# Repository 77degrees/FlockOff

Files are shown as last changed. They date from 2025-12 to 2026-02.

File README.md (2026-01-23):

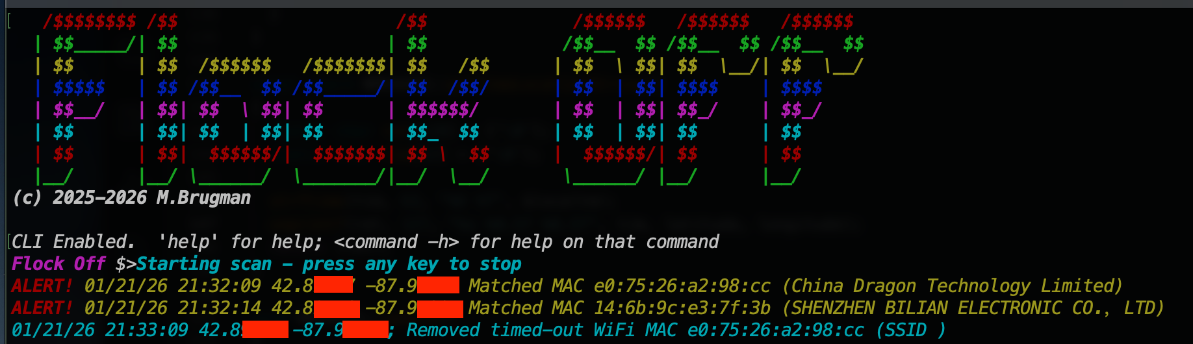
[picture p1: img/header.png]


# FlockOff
This project started as a device specifically to detect Flock security ALPR devices, but has grown into a more generic WiFi/Bluetooth LE scanner/alert wardriving tool.

## Description
This started of strictly as a Flock detector, but grew into more.  In general, it is a device to monitor WiFi and BTLE networks, setting an indicator whenever a broadcaster is found that meets preset parameters.  For WiFi networks, those parameters can be a MAC OID or network name (SSID).  For Bluetooth, the matching criteria can be name, MAC, or by specific 16-bit UUIDs.

The hardware device consists of an ESP32-S3 dev board, a serial GPS module, and two LEDs for alerts and status.

There is a serial interface to the hardware device with a rich CLI (command-line interface).  The device can also be used stand-alone (results are stored to internal file system) or by scripting.

## Project structure
The files contained in the project:
+ `./hardware` - contains a KiCad project for the board
+ `./img` - images used in this README
+ `./py` - simply python3 script to interact with the flocker (notes below)
+ `./src` - source code (arduino project) for the ESP32 (notes below)
+ `./case` - sample 3D printer `.stl` and openSCAD files for a case

### Hardware
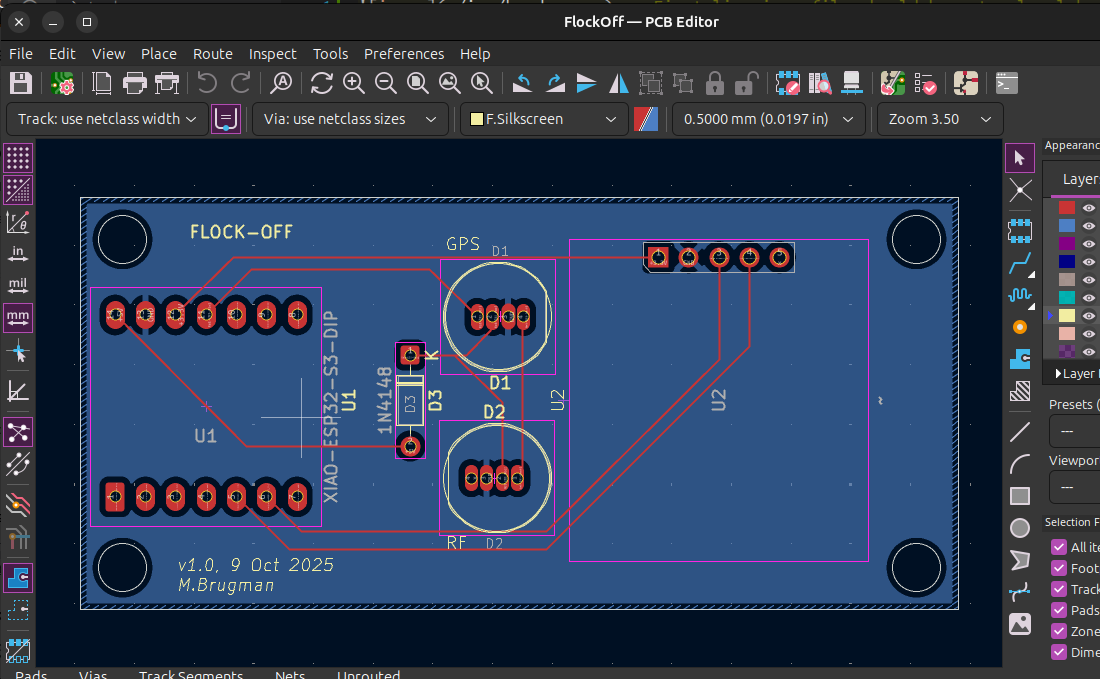
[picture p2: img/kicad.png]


The hardware is dead simple - two dev modules, two through-hole 8mm WS2812 LEDs, and a small signal diode:
+ [ESP32-S3](https://www.amazon.com/Dual-core-Supported-Efficiency-Interface-Robotics/dp/B0DJ6NQFKX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) I picked this module because of small size, good price, and 8MB of both flash and PSRAM
+ [GPS Module](https://www.amazon.com/hiBCTR-Navigation-Positioning-Microcontroller-Sensitivity/dp/B0FL71WTQY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) There is nothing special about this particular module; it is a basic GPS with NMEA serial interface, it was cheap, and in stock at Amazon
+ [WS1812 LEDs](https://www.adafruit.com/product/1734)  These are interesting in that they are the typical addressable LEDs, but in a through-hole 8mm package.  They are great for using as status indicators.  Also handy because there are so many libraries to work with them.
+ [1N4148 Diode](amazon.com/ALLECIN-1N4148-Schottky-Switching-Package/dp/B0CKRMK45V/ref=sr_1_6_sspa?dib=eyJ2IjoiMSJ9.5f18Rx_7lMSBN-40Nk5_scirzd5gVqG_sr48GsP-pxJ7RyARr5GHbm76WgpJle4ywCwcEGfv6m5ZR-PIBoBmRN28qtEe29DQYY84c263_q6oFDujaGGVK8-qabhrRd_IZtu2PwFHkKMBdiIw8IDQjSYkBxPm9DKi_AA6exCA7rmOiWGNdN9Oq0D-5c1H1XGK1kBii_ftCc-F3YiORaBovQ5vkFW9kAN3zzAu7IgDKEk.RF6rc4KmtAVvY9uUuLV-Zf6xt-HBLaOGQf1vvRW5V2U&dib_tag=se&keywords=1n4148&qid=1765833550&sr=8-6-spons&sp_csd=d2lkZ2V0TmFtZT1zcF9tdGY&psc=1) (Amazon link for reference, I had some in my parts bin).  This is used because it has a forward voltage drop of about .7V.

#### What's up with the diode?
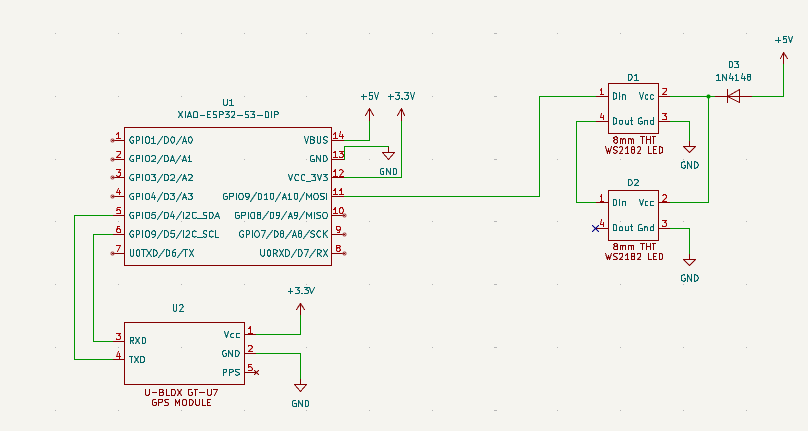
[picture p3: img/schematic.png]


Like pretty much all WS2812 LEDs, these need 5VDC to operate; 5VDC power, 5VDC data line.  The ESP32 is a 3.3 microcontroller, so what to do?

The USB connection supplies 5V which is regulated down to 3.3V for the microcontroller and associated stuff.  In the schematic above, `D3` is shown between the 5V USB power and the LED power in pin; that drops the voltage to about 4.3VDC.  That's just within spec for the LED, and it is still plenty bright.

The 3.3V signal data line from the ESP32 would be too low if the LED was powered by 5V, but is within spec for the LED when it is running at 4.3-ish volts.  It's a cheat to get away without having to use level converters; not something I'd do for a "real" production project, but good enough for here.

### Firmware
The firmware is written using the Arduino IDE.  In the past, I've always avoided that and used VS Code with my own Makefile or CMAKE, PlatformIO, or whatever.  I decided to go with Arduino in this case because I'm very unhappy with the integration of Copilot into VS Code (and really, the push to shove AI into everything).  For now, Ardiuno is just code.

For more specific information, see the `DEVELOPING.md` file.

### CLI Interface
There is a CLI available at the USB port at 115200/8N1.  The CLI uses ANSII escape codes for color, has tab-completion, up-arrow recall, and help:
```  
Flock Off $>help 
Use 'command -h' for detailed help on each command
        help - Print list of commands
        version - Display firmware version
        survey - Perform WiFi survey
        scan - Start continuous scan
        clear - Clear the console
        reset - Reboot the device
        ls - List files
        rm - Delete file
        write - Write test file
        mv - Rename file
        cp - Copy file
        cat - Cat file
        status - Get system status
        config - Get/Set config values
        criteria - Get/Set target matching criteria
```  
Passing a `-h` to any command will show help for that command, for example:
```  
Flock Off $>survey -h
survey [OPTION]
Perform a WiFi and/or Bluetooth survey.  Displays all results, not just those that match scan criteria.

  -i <INTERVAL>   interval in milliseconds to scan each WiFi channel
  -f <FILENAME>   save results to FILENAME in JSON format
  -n <NOTES>      add NOTES added for reference

If the -f parameter is not passed, JSON results will be displayed in the terminal.
```  
There is a flat filesystem included (flat, meaning no directories; all files are in a single directory). Basic Linux-type file management commands are available, but note that there is no 'globbing'; all filenames must be directly entered.  Examples:
```  
      371  01/22/26  18:25:46  autoscan.1.log
      163  01/22/26  18:42:01  autoscan.log
      208  12/31/69  18:02:32  config.json
    11300  01/22/26  18:26:04  system.1.log
    11107  01/22/26  18:25:30  system.2.log
    11347  01/22/26  18:43:37  system.log
Flock Off $>cat config.json
{"deviceName":"Super Secret Sniffer","timeZone":"CST6CDT,M3.2.0,M11.1.0","LEDBrightness":100,"debugEnabled":true,"debugLogRollCount":3,}
Flock Off $>
```  
Configuration is menu-driven:
```  
Flock Off $>config 
1) Set device name (Super Secret Sniffer)
2) Set timezone (CST6CDT,M3.2.0,M11.1.0)
3) Set max LED brightness (100)
4) Set debug logging (enabled)
5) Set scan logging (enabled)
6) Set debug file rolling count (3)
7) Set scan file rolling count (10)
8) Set minimum RSSI (-90)
9) Set minimum alert time (60)
Select number of item to change or 'x' to exit with no changes: 
```  
## LEDs
What do the LEDs do?
### GPS LED
| color | description |  
|---|---|
| Green blink | GPS Fix good, communication good |  
| Purple blink | GPS no fix, communication good |  
| Red blink | No comms to GPS module |  

### RF LED
| color | description |  
|---|---|
| Blue fade alert | Survey in progress | 
| Steady blue | Continuous scan in progress |  
| Alternating blue/purple | Continuous scan detecting target |  

## Continuous scans
The default action for the device is to continuously scan for targets in the area.  There are two ways to start a scan:
+ Power up the device, if no input is seen on the CLI in the first 5 seconds, continuous scanning will automatically begin
+ Using the `scan` command to start continuous scanning

### Stopping a scan
Press any key will connected to the serial port to stop the scan

### Scan logging and information
The RF LED will glow continuously blue when a scan is running.  If a target is seen, the LED will alternate blue/purple.  As targets are seen and "disappear" they will be listed in the serial terminal.  If enabled in configuration, the data will also be saved in rolling files in the filesystem - this allows "headless" operation with the ability to look at the results later.

Sample output in the serial terminal:
```  
Flock Off $>Starting scan - press any key to stop
ALERT! 01/23/26 01:03:13 42.8XXXX -87.9XXXX Matched MAC 14:6b:9c:e3:7f:3b (SHENZHEN BILIAN ELECTRONIC CO.，LTD)
```  

Sample scan log:  
```  
Flock Off $>ls 
      267  01/22/26  19:02:59  autoscan.1.log
      163  01/22/26  18:42:01  autoscan.2.log
      371  01/22/26  18:25:46  autoscan.3.log                                             
      267  01/22/26  19:04:01  autoscan.log                                               
      208  12/31/69  18:02:32  config.json                                                
     4557  01/22/26  18:50:13  survey.example.json                                        
    12384  01/22/26  19:03:01  system.1.log                                               
    11300  01/22/26  18:26:04  system.2.log
    11215  01/22/26  19:04:01  system.log
Flock Off $>cat autoscan.log
[00007907] 01/22/26 19:03:13 LOGGER::Started logger
[00007950] 01/22/26 19:03:13 WIFI::01/23/26 01:03:13 42.8XXXX -87.9XXXX; Matched mac 14:6b:9c:e3:7f:3b
[00055504] 01/22/26 19:04:01 SCAN::Ending scan, closing log.
[00055516] 01/22/26 19:04:01 LOG::Closing log!
```  

## Performing a site survey
A survey will report all WiFi and BTLE broadcasters in range.  Why perform a survey?  Maybe there's a known device that isn't triggering alerts, and we want to characterize it (find MAC address, if BT, see if there are any service UUIDs it's broadcasting).

Basic steps:
1) Connect to the device with a serial terminal of your choice (PuTTY on Windows, TIO/minicom on Linux, minicom on MAC).
2) Use the `status` command to be sure GPS has gotten a fix and that the data looks correct (GPS coordinates masked by me for privacy):
``` 
Flock Off $>status 
->Hardware:
        Chip model ESP32-S3
        Chip frequency 240 MHz
        Core count 2 cores
->GPS:
        GPS current coordinates are 42.8XXXX, -87.9XXXX
        GPS current time/date (gmt) is 00:47:52 1/23/2026
        Number of satellites currently tracked: 9
->Filesystem:
        Total capacity 4194304bytes, 53248 used (4044 KiB free)
->Memories:
        Internal total heap 324436 bytes, 88536 used (230 KiB free)
        PSRAM total heap 8388608 bytes, 58280 used (8192 KiB free)
->Wall clock:
        Current wall clock time is Thu, 22 Jan 2026 18:47:51 -0600
        Timezone is set to CST6CDT,M3.2.0,M11.1.0
```  
3) Use the `survey` command to start the survey.  Parameters are:
   + `-i INTERVAL` defines how much time (milliseconds) to spend on each WiFi channel
   + `-n NOTES` to save the results in a JSON file, with survey notes set to `NOTES`
   + `-f FILENAME` to save results
```  
Flock Off $>survey -i 2000 -n 'Example survey' -f survey.example.json
Survey starting
Survey done, found 16 WiFi devices, 13 Bluetooth devices.
Saving survey results to survey.example.json
Wrote 4557 bytes to file
```  
This example survey found 16 WiFi devices and 13 BTLE devices.  The data in the JSON file looks like this:  
```
Flock Off $>cat survey.example.json
{"SurveyNotes":"'Example survey","Device":"Super Secret Sniffer","LocationLongLat":[-87.9XXXX,42.8XXXX],"SatelliteCount":9,"DateTime":"2026-01-22 18:50:13","Timezone":"CST6CDT,M3.2.0,M11.1.0","DataVersion":2,"WiFiDevices":[{"Method":"WiFi","Type":"Data","Subtype":"ND (null no data)","SSID":"","SourceAddr":"4a:43:76:15:87:dd","DestAddr":"a0:36:bc:db:ca:a4","Channel":10,"RSSI":-20},{"Method":"WiFi","Type":"Management","Subtype":"beacon","SSID":"Open Wheel","SourceAddr":"08:36:c9:ed:b8:65","DestAddr":"ff:ff:ff:ff:ff:ff","Channel":4,"RSSI":-87},{"Method":"WiFi","Type":"Management","Subtype":"beacon","SSID":"NETGEAR05-Guest","SourceAddr":"c2:18:65:d2:d2:b2","DestAddr":"ff:ff:ff:ff:ff:ff","Channel":2,"RSSI":-87},{"Method":"WiFi","Type":"Data","Subtype":"Data","SSID":"","SourceAddr":"b2:28:aa:1c:0a:2a","DestAddr":"01:80:c2:00:00:00","Channel":1,"RSSI":-63},{"Method":"WiFi","Type":"Management","Subtype":"beacon","SSID":"flu","SourceAddr":"b2:28:aa:1c:0a:29","DestAddr":"ff:ff:ff:ff:ff:ff","Channel":1,"RSSI":-63},{"Method":"WiFi","Type":"Data","Subtype":"Data","SSID":"","SourceAddr":"a0:36:bc:db:ca:a0","DestAddr":"01:80:c2:00:00:00","Channel":6,"RSSI":-45},{"Method":"WiFi","Type":"Management","Subtype":"beacon","SSID":"virus","SourceAddr":"a0:36:bc:db:ca:a0","DestAddr":"ff:ff:ff:ff:ff:ff","Channel":6,"RSSI":-45},{"Method":"WiFi","Type":"Management","Subtype":"beacon","SSID":"flu_IoT","SourceAddr":"b2:28:aa:1c:0a:2a","DestAddr":"ff:ff:ff:ff:ff:ff","Channel":1,"RSSI":-64},{"Method":"WiFi","Type":"Data","Subtype":"QoS Data","SSID":"","SourceAddr":"b2:28:aa:1c:0a:29","DestAddr":"e0:75:26:a2:98:cc","Channel":1,"RSSI":-63},{"Method":"WiFi","Type":"Data","Subtype":"QoS Data","SSID":"","SourceAddr":"14:6b:9c:e3:7f:3b","DestAddr":"b2:28:aa:1c:0a:29","Channel":1,"RSSI":-54},{"Method":"WiFi","Type":"Data","Subtype":"QoS Data","SSID":"","SourceAddr":"cc:db:a7:93:ec:2c","DestAddr":"a0:36:bc:db:ca:a0","Channel":7,"RSSI":-71},{"Method":"WiFi","Type":"Management","Subtype":"beacon","SSID":"<HIDDEN>","SourceAddr":"cc:28:aa:1c:0a:28","DestAddr":"ff:ff:ff:ff:ff:ff","Channel":1,"RSSI":-63},{"Method":"WiFi","Type":"Data","Subtype":"Data","SSID":"","SourceAddr":"a0:8a:06:6f:ec:fa","DestAddr":"01:00:5e:00:00:07","Channel":6,"RSSI":-84},{"Method":"WiFi","Type":"Data","Subtype":"Data","SSID":"","SourceAddr":"cc:28:aa:1c:0a:28","DestAddr":"01:80:c2:00:00:00","Channel":1,"RSSI":-64},{"Method":"WiFi","Type":"Data","Subtype":"ND (null no data)","SSID":"","SourceAddr":"e0:75:26:a2:98:cc","DestAddr":"b2:28:aa:1c:0a:29","Channel":1,"RSSI":-76},{"Method":"WiFi","Type":"Management","Subtype":"beacon","SSID":"NETGEAR05","SourceAddr":"94:18:65:d2:d2:b1","DestAddr":"ff:ff:ff:ff:ff:ff","Channel":2,"RSSI":-90}],"BLEDevices":[{"Method":"BTLE","Name":"N00DM","MAC":"c7:06:90:c0:c4:6c","RSSI":-84,"UUID16bit":[65199],"UUID128bit":[],"DataUUID16bit":[65199],"DataUUID128bit":[]},{"Method":"BTLE","Name":"OfficeJet 5200 series","MAC":"86:a9:3e:bc:5c:c9","RSSI":-86,"UUID16bit":[65144],"UUID128bit":[],"DataUUID16bit":[],"DataUUID128bit":[]},{"Method":"BTLE","Name":"","MAC":"47:d1:13:3a:79:de","RSSI":-70,"UUID16bit":[],"UUID128bit":[],"DataUUID16bit":[],"DataUUID128bit":[]},{"Method":"BTLE","Name":"","MAC":"6b:7a:e6:9b:f5:d2","RSSI":-65,"UUID16bit":[],"UUID128bit":[],"DataUUID16bit":[],"DataUUID128bit":[]},{"Method":"BTLE","Name":"","MAC":"66:95:29:56:70:e9","RSSI":-69,"UUID16bit":[],"UUID128bit":[],"DataUUID16bit":[],"DataUUID128bit":[]},{"Method":"BTLE","Name":"","MAC":"d4:0a:5d:22:d4:e9","RSSI":-61,"UUID16bit":[],"UUID128bit":[],"DataUUID16bit":[],"DataUUID128bit":[]},{"Method":"BTLE","Name":"","MAC":"63:13:27:3d:4d:22","RSSI":-62,"UUID16bit":[],"UUID128bit":[],"DataUUID16bit":[],"DataUUID128bit":[]},{"Method":"BTLE","Name":"","MAC":"1d:2a:e8:54:5e:f4","RSSI":-69,"UUID16bit":[],"UUID128bit":[],"DataUUID16bit":[65267],"DataUUID128bit":[]},{"Method":"BTLE","Name":"","MAC":"a8:51:ab:c6:11:25","RSSI":-75,"UUID16bit":[],"UUID128bit":[],"DataUUID16bit":[],"DataUUID128bit":[]},{"Method":"BTLE","Name":"","MAC":"3c:5c:ae:fd:ff:0d","RSSI":-53,"UUID16bit":[],"UUID128bit":[],"DataUUID16bit":[64753],"DataUUID128bit":[]},{"Method":"BTLE","Name":"","MAC":"79:d2:f7:d7:5d:22","RSSI":-75,"UUID16bit":[],"UUID128bit":[],"DataUUID16bit":[],"DataUUID128bit":[]},{"Method":"BTLE","Name":"","MAC":"32:2b:12:15:81:9a","RSSI":-51,"UUID16bit":[],"UUID128bit":[],"DataUUID16bit":[64753],"DataUUID128bit":[]},{"Method":"BTLE","Name":"[TV] Samsung 8 Series (65)","MAC":"8c:ea:48:a7:2c:03","RSSI":-72,"UUID16bit":[],"UUID128bit":[],"DataUUID16bit":[],"DataUUID128bit":[]}]}
```  
### Interpreting survey results
The included python scripts can pull the survey data from the device and populate some database tables (sqlite3) for analysis.

To do this, start by going to the `./py` directory and running the script.  There are some Python modules needed; they can be installed with the included requirements file (`pip3 install -r requirements.txt`)

*Note - it is always recommended to use a virtual environment with python scripts that require different modules.  See python documentation on how to create and use a virtual environment if necessary.*

Start by listing the files on the device (make sure you are no longer connected to it by serial terminal):
```  
┌──(venv)─(matty💊s76)-[~/data/projects/FlockOff/py]
└─$ python3 ./flock.py --dbfile example.db --port /dev/ttyACM0 --dir                
config.bak
config.json
survey.00.json
survey.01.json
survey.example.json
system.log
```  
The parameters to the `flock.py` script are:
+ `--port PORT` - the serial port of the connected device
+ `--dbfile FILE` - name of the database file to use (it will be created if it does not exist).  This is only required if the `load` command is issued.
+ Command - this is one of a few commands:
  + `--dir` - list the files on the device
  + `--cat FILE` - list the contents of the specified file
  + `--load FILE` - load the specified JSON file into database tables'
  + `--download FILE` - download the specified FILE from the device to the local filesystem.  The local copy will have the same name as the file on the device.

The above `--dir` command showed our `survey.example.json` from the survey.  Let's load it into the database tables:
```  
┌──(venv)─(matty💊s76)-[~/data/projects/FlockOff/py]
└─$ python3 ./flock.py --dbfile example.db --port /dev/ttyACM0 --load survey.example.json
Loaded 12 WiFi devices, 21 BTLE devices from survey "'Example" at 2025-12-15 15:56:52
```  

Note that if the database file didn't exist before this command, the script will also populate the data tables with the YAML and JSON files for known manufacturer OID and UUID data.

### Survey database
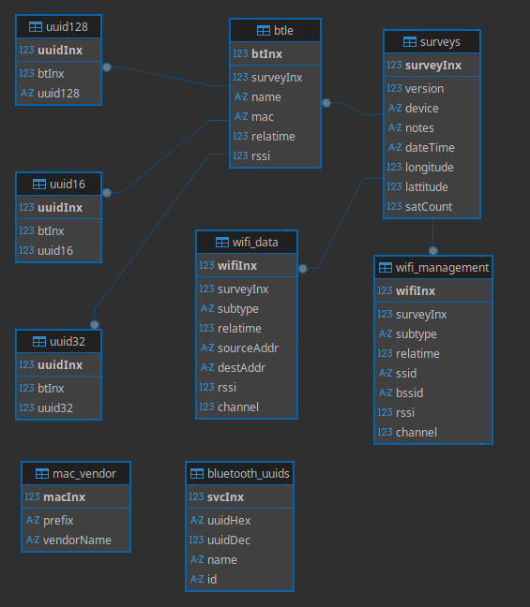
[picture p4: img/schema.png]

The database schema can be seen in `./src/py/survey.db.schema`

The sqlite3 database can be explored with a gui tool or the command line.  The `surveys` table shows basic information about the a survey json file (using `sqlite3` command line tool):
```  
sqlite> .mode box
sqlite> .headers on
sqlite> select * from surveys;
┌───────────┬──────────┬─────────────────────┬───────────┬───────────┬──────────┐
│ surveyInx │  notes   │      dateTime       │ longitude │ lattitude │ satCount │
├───────────┼──────────┼─────────────────────┼───────────┼───────────┼──────────┤
│ 1         │ 'Example │ 2025-12-15 15:56:52 │ 42.0001   │ -87.0001  │ 8        │
└───────────┴──────────┴─────────────────────┴───────────┴───────────┴──────────┘
```  
 The `surveyInx` field is a foreign key into the `wifi_data`, `wifi_management` and `btle` tables.  This allows multiple surveys to be loaded into a single database file

`notes` is the value from the `-j NOTES` parameter of the `survey` command.  `dateTime`, `longitude`, `lattitude`, and `satCount` are populated by the GPS module.

`wifi_data` contains all captured WiFi Data packets; `wifi_management` contains all captured WiFi Management packets (think access point beacons, probe responses, etc.).  They can be joined to find all devices and the access points to which they are connected:   
```
select distinct sta.subtype "station data subtype",
		ap.ssid "AP SSID", 
		ap.bssid "AP BSSID", 
		sta.sourceAddr "station MAC", 
		sta.channel "CH",
		mv.vendorName "station vendor" 
from wifi_data sta
join wifi_management ap on ap.bssid = sta.destAddr and ap.channel = sta.channel and ap.surveyInx = sta.surveyInx
left join mac_vendor mv on mv.prefix like substr(sta.sourceAddr, 1, 8) 
where sta.surveyInx = 2
order by ap.bssid;

┌──────────────────────┬────────────────────┬───────────────────┬───────────────────┬────┬────────────────────────────────────────┐
│ station data subtype │      AP SSID       │     AP BSSID      │    station MAC    │ CH │             station vendor             │
├──────────────────────┼────────────────────┼───────────────────┼───────────────────┼────┼────────────────────────────────────────┤
│ ND (null no data)    │ virus              │ a0:36:bc:db:ca:a0 │ cc:db:a7:93:ec:2c │ 6  │ Espressif Inc.                         │
│ QoS Data             │ virus              │ a0:36:bc:db:ca:a0 │ cc:db:a7:93:ec:2c │ 6  │ Espressif Inc.                         │
│ ND (null no data)    │ SpectrumSetup-ECFD │ a0:8a:06:6f:ec:fa │ bc:35:1e:77:8a:9f │ 6  │ Tuya Smart Inc.                        │
│ ND (null no data)    │ SpectrumSetup-ECFD │ a0:8a:06:6f:ec:fa │ 30:fc:eb:84:38:ce │ 7  │ LG Electronics (Mobile Communications) │
│ ND (null no data)    │ SpectrumSetup-ECFD │ a0:8a:06:6f:ec:fa │ 30:fc:eb:84:38:ce │ 6  │ LG Electronics (Mobile Communications) │
│ QoS Data             │ flu                │ b2:28:aa:1c:0a:29 │ e0:75:26:a2:98:cc │ 1  │ China Dragon Technology Limited        │
│ ND QoS               │ flu                │ b2:28:aa:1c:0a:29 │ 14:6b:9c:e3:7f:3b │ 2  │ SHENZHEN BILIAN ELECTRONIC CO.，LTD    │
│ QoS Data             │ flu                │ b2:28:aa:1c:0a:29 │ 14:6b:9c:e3:7f:3b │ 1  │ SHENZHEN BILIAN ELECTRONIC CO.，LTD    │
│ QoS Data             │ flu                │ b2:28:aa:1c:0a:29 │ 18:b4:30:a0:24:fa │ 1  │ Nest Labs Inc.                         │
└──────────────────────┴────────────────────┴───────────────────┴───────────────────┴────┴────────────────────────────────────────┘
```

The `btle` table contains bluetooth broadcasters:
```  
sqlite> select b.name, b.mac, b.rssi from btle as b join surveys s on b.surveyInx = s.surveyInx order by b.mac;
┌───────────────────────┬───────────────────┬──────┐
│         name          │        mac        │ rssi │
├───────────────────────┼───────────────────┼──────┤
│                       │ 01:c5:61:6d:2c:b4 │ -53  │
│                       │ 04:a0:29:10:68:e4 │ -78  │
│                       │ 08:66:98:f2:a3:ba │ -84  │
│                       │ 34:fe:3e:a1:f5:e2 │ -63  │
│                       │ 56:f6:b3:ad:60:5f │ -82  │
│                       │ 66:7f:66:1d:ec:ce │ -68  │
│                       │ 6d:67:db:fd:9e:67 │ -84  │
│                       │ 6e:d3:64:c3:af:77 │ -79  │
│                       │ 77:50:8c:84:fa:72 │ -45  │
│                       │ 78:90:0b:c0:26:1b │ -69  │
│                       │ 7e:91:43:7c:ff:bf │ -75  │
│ OfficeJet 5200 series │ 86:a9:3e:bc:5c:c9 │ -76  │
│                       │ 8c:ea:48:a7:2c:03 │ -73  │
│                       │ a8:51:ab:c6:11:25 │ -82  │
│                       │ c0:c9:9b:f2:d7:43 │ -75  │
│                       │ c1:cf:e2:c9:64:5f │ -85  │
│                       │ ca:ba:59:12:f6:0d │ -66  │
│ N00DM                 │ ce:a3:ad:95:04:29 │ -80  │
│                       │ d5:93:9d:03:9f:f5 │ -80  │
│                       │ ea:a8:d0:6f:67:89 │ -84  │
│                       │ ec:9d:4d:3c:28:2b │ -68  │
└───────────────────────┴───────────────────┴──────┘
```  
There are quite a few BTLE devices found.  To narrow it down to those that are broadcasting a UUID:
```  
sqlite> select b.name, b.mac, u.uuid16 from btle b join uuid16 u on b.btInx = u.btInx where b.surveyInx = 1 order by b.mac;
┌───────────────────────┬───────────────────┬────────┐
│         name          │        mac        │ uuid16 │
├───────────────────────┼───────────────────┼────────┤
│ OfficeJet 5200 series │ 86:a9:3e:bc:5c:c9 │ 65144  │
│ N00DM                 │ ce:a3:ad:95:04:29 │ 65199  │
└───────────────────────┴───────────────────┴────────┘
```

**More SQL examples can be found in `./example.sql`**

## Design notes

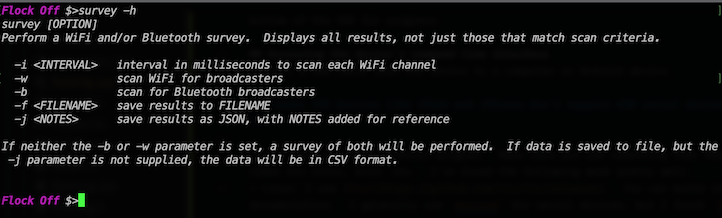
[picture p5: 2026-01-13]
img/terminal2.png

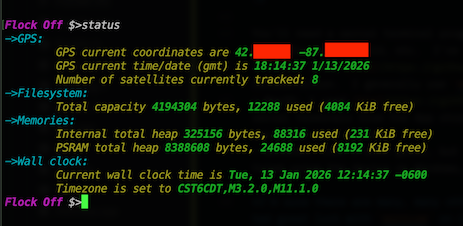
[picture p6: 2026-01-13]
img/terminal.png

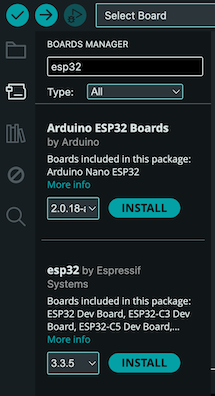
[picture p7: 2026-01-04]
img/boards.png

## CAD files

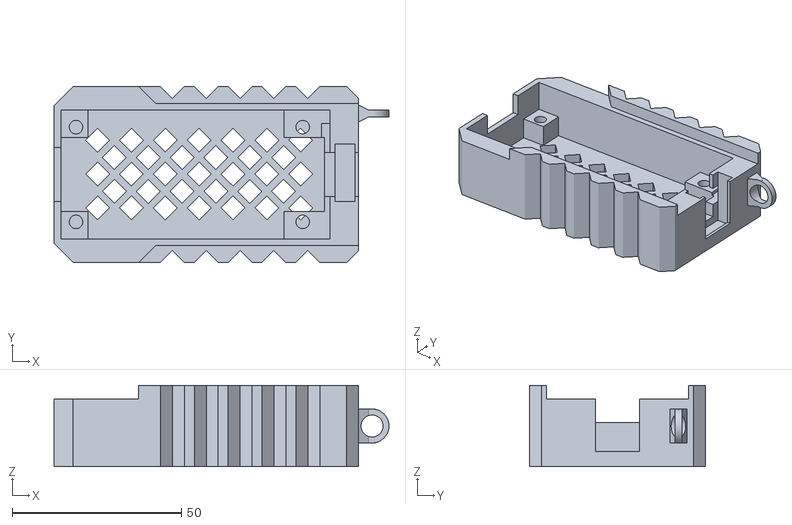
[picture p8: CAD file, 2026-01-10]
case/bottom.stl
99.0 x 52.0 x 24.0

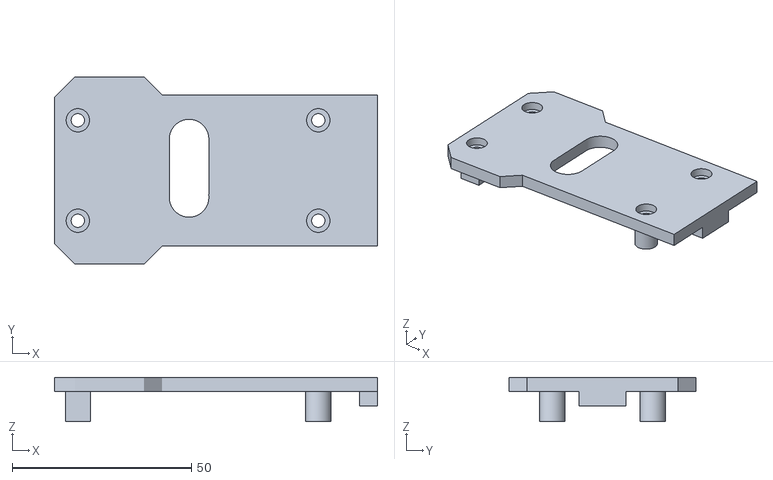
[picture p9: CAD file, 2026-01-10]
case/top.stl
90.0 x 52.0 x 12.4

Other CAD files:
case/case.scad

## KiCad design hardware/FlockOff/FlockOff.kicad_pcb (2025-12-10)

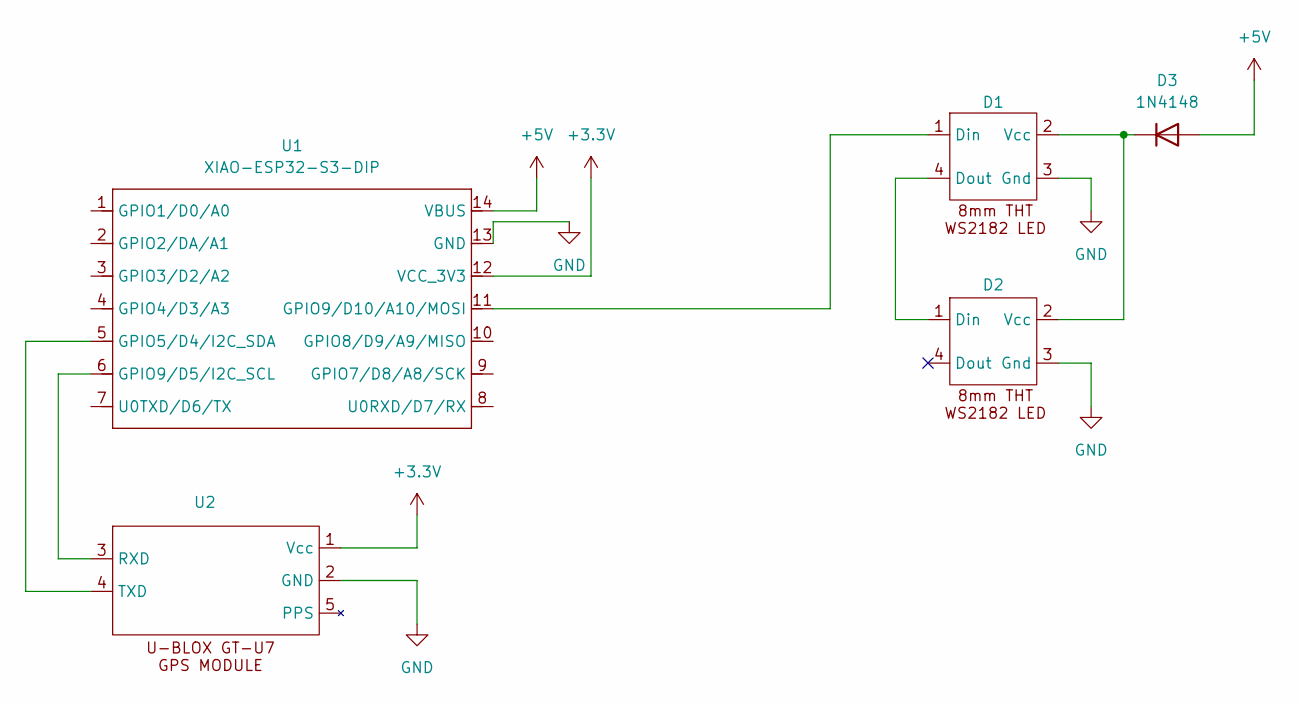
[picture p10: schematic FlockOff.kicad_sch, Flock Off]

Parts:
D1, D2: LED_D8.0mm_WS2812
D3: 1N4148; D_DO-35_SOD27_P7.62mm_Horizontal
U1: XIAO-ESP32-S3-DIP; MOUDLE14P-XIAO-DIP-SMD
U2: GPS_Module

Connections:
+3.3V: U1.12 (VCC_3V3), U2.1 (Vcc)
+5V: D3.2 (A), U1.14 (VBUS)
GND: D1.3 (Gnd), D2.3 (Gnd), U1.13 (GND), U2.2 (GND)
unnamed: D1.1 (Din), U1.11 (GPIO9/D10/A10/MOSI)
unnamed: D1.4 (Dout), D2.1 (Din)
unnamed: D1.2 (Vcc), D2.2 (Vcc), D3.1 (K)
unnamed: U1.5 (GPIO5/D4/I2C_SDA), U2.4 (TXD)
unnamed: U1.6 (GPIO9/D5/I2C_SCL), U2.3 (RXD)

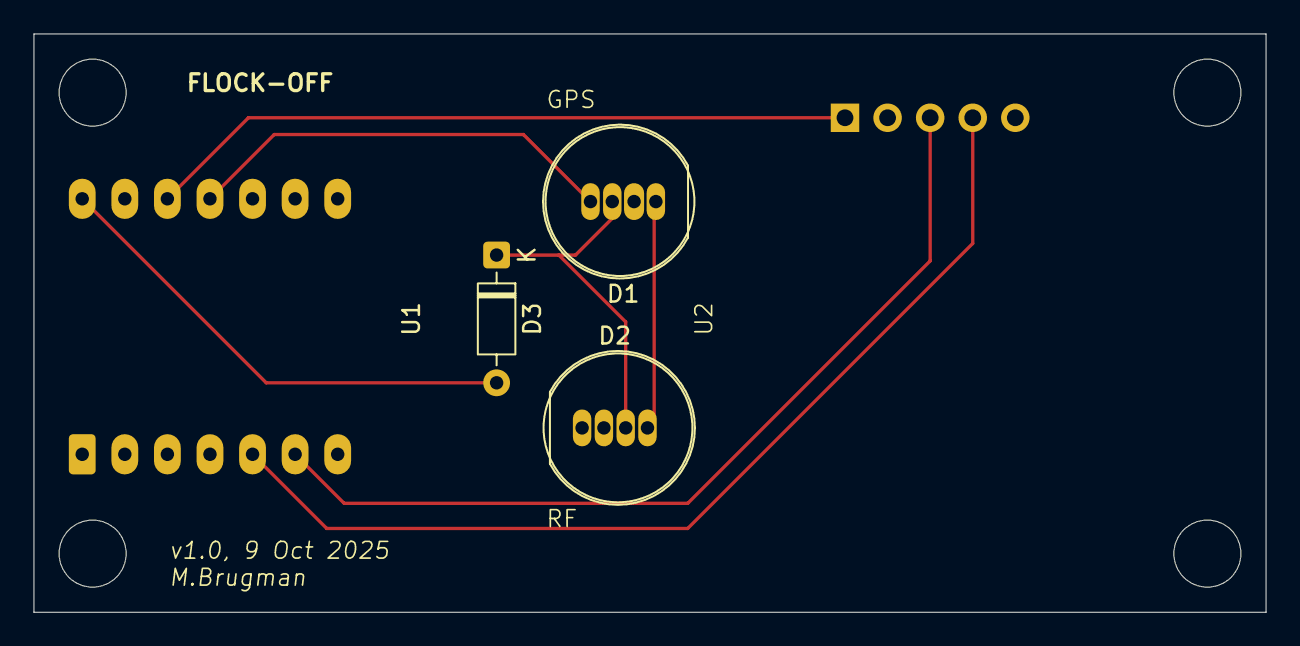
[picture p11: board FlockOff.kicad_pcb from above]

Board: 2 copper layers, 73.5 x 34.5 mm, 5 parts (0 on the bottom side), 8 nets.

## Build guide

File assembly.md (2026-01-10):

# Some general notes on constructing the device
## PCB
The `./hardware` folder has a KiCAD project for the PCB.  This should be sufficient if you are using the components listed in the `README.md` file.  (Yeah, I'll make a BOM at some point).  KiCAD can be used to generate gerber files for a board house or home fab (if you have those capabilities).  The original prototypes were done at [OSHPark](https://oshpark.com).  With standard service, the total was just under $20USD for 3 boards and took about 3 weeks for them to arrive.

The board has four 4mm through holes in the corners for mounting.  This drawing shows the dimensions of the board, locations of the mounting holes, and the center point of the two 8mm LEDs (all dimensions in millimeters):
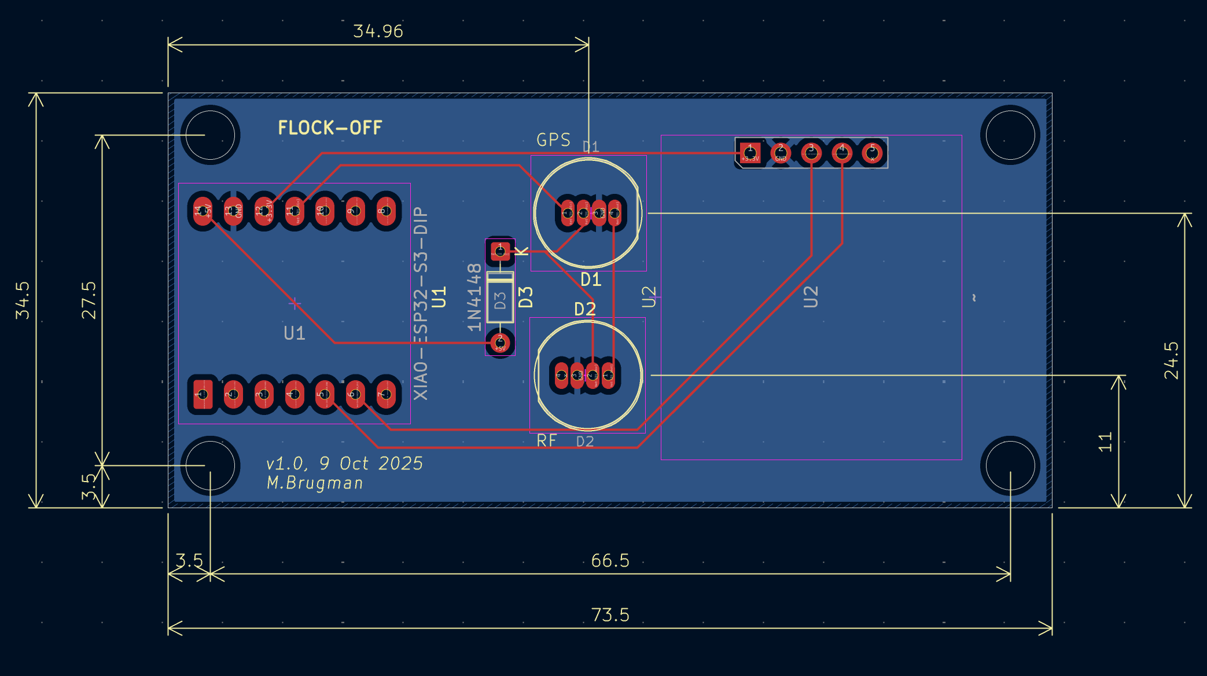
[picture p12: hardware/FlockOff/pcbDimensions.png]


## Soldering
The board is designed with all through-hole components for easy home soldering.  The only tricky components are the two LEDs; they are 0.050" pitch, so be sure to use a fine point on the soldering iron and a bit of flux to prevent solder bridges.  Everything else is on 0.100" pitch and one PTH component.

When soldering the LEDs, be mindful of the flat edge of the base - align that side of the LED with the flat on the silkscreen of the PCB. Note that they are in opposite orientations!

## Case/Enclosure
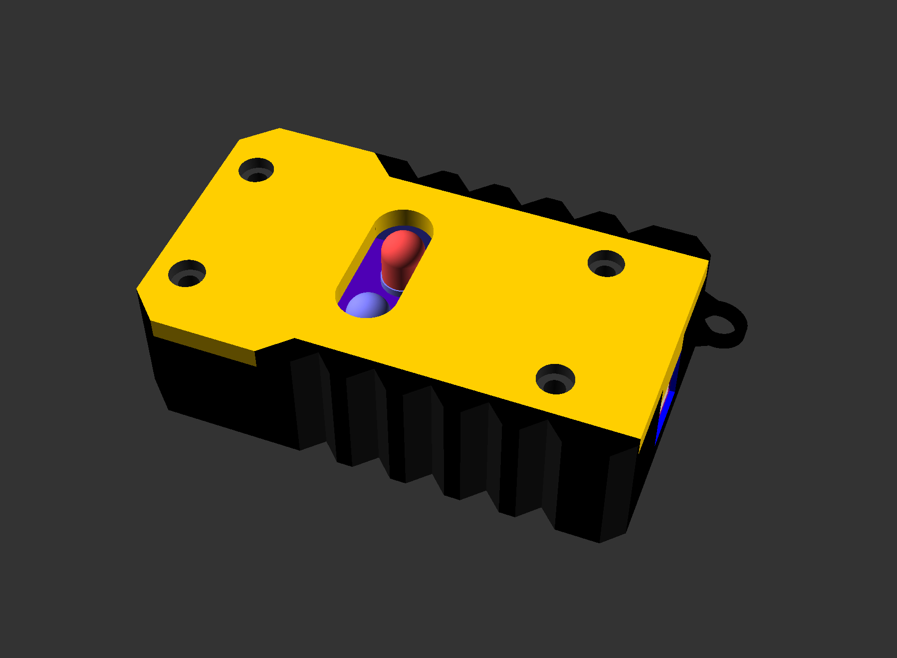
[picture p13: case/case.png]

The `./case` folder has an OpenSCAD file for a sample enclosure, with included `.stl` files.  Feel free to use that one, remix it, make your own, or don't use one at all.

If you are using the included OpenSCAD file, look for `main` near the end of the file.  The file is the complete enclosure, along with a very rough representation of the PCB and GPS antenna for reference.  When working with the file, you can show/hide different parts by simply commenting/uncommenting lines in `main`:
```  
module main()
{
    // the whole shebang
    bottom(90, 42, 20);
    top(90, 42, 4, 20);
    pcb(-5, 0, 10);
    antenna();
    lanyardRing(42, 18, 12);
    //posts();
}
```  
For example, commenting out everything but `bottom()` will turn off everything except the geometry for the bottom part of the enclosure.

The sample enclosure is held together with 4 3mm SHCS and requires 4 3mm threaded inserts to placed in the bottom.

The OpenSCAD file isn't the cleanest thing I've ever written.  I use OpenSCAD because it is very intuitive to me and I don't want to take the time to learn something like FreeCad :)

If you come up with a different enclosure, feel free to add it here with a PR.

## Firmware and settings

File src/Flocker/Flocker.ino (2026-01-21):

/***********************************************************************
* Main entry point for the flocker.
***********************************************************************/
#include "gps.h"
#include "led.h"
#include "cli.h"
#include "flockFs.h"
#include "flockCfg.h"
#include "scanner.h"
#include "flockLog.h"
#include "targets.h"

// constants for config'ing objects
#define GPS_PORT_TX 5        // defined by circuit board - don't change unless you changed hardware
#define GPS_PORT_RX 6        // defined by circuit board - don't change unless you changed hardware
#define GPS_PORT_BAUD 9600   // baud rate for GPS module - don't change unless you're using a different module
#define ADDR_LED_PIN 9       // defined by circuit board - don't change unless you changed hardware
#define USER_LED 21          // built-in user LED on XIAO ESP32S3 module

// global class instances
FLOGGER flockLog;
NMEAGPS gps;
MBFS flockfs;
CONFIG flockCfg;
SCANNER flockScan;
LEDS flockLED;
TARGETS scanTargets;
bool psRamInitOk;
bool initOk;

static uint8_t cfgListenerID = BAD_LISTENER_ID;
static uint32_t bootTick;
static bool allowAutoScan = true;

// if you see this message on the CLI, you messed up an allocation!
void heapCheck() {
  if (!heap_caps_check_integrity_all(true)) {
    Serial.printf("HEAPCHK->HEAPS FUCKED!\r\n");
  }
}

// Arduino setup method - called once by embedded OS on startup
void setup() {
  initOk = true;
  psRamInitOk = psramInit();
  pinMode(USER_LED, OUTPUT);
  Serial.begin(112500);  // init USB serial
  delay(2000);

  // order is important here - don't change this order!
  initOk &= gps.begin(GPS_PORT_BAUD, GPS_PORT_RX, GPS_PORT_TX);
  initOk &= flockfs.begin();
  initOk &= flockCfg.begin();
  initOk &= flockLog.begin(200, "system", flockCfg.getDebugFileCount());
  initOk &= flockScan.begin();
  initOk &= flockLED.begin(ADDR_LED_PIN, 140);
  initOk &= setupCLI();
  initOk &= scanTargets.begin();

  if (!initOk)
  {
    delay(2000);
    Serial.printf("SOMETHING DIDN'T INIT.  Try turning debug logging on :/\r\n");
    delay(2000);
  }
  else
  {
    flockCfg.registerListener(cfgListenerID);
  }

  bootTick = millis();

  flockLog.addLogLine("main", "Leaving setup()\r\n");
}

void busyDelayLoop(uint32_t delay)
{
  uint32_t offset = millis();

  while ((millis() - offset) < delay)
  {
    gps.update();
    flockLED.update();
    updateCLI();
    flockLog.update();
  }
}

// Arduino-defined main loop.  Called continuously by embedded OS
void loop() {
  static uint32_t msFlash = millis();
  static uint32_t msHeap = millis() - 1000;

  // update classes
  if (initOk)
  {
    gps.update();
    flockLED.update();
    updateCLI();
    flockLog.update();
    flockScan.update();

    // if no CLI action seen in the first 5 seconds,
    // start a continuous scan process
    if (allowAutoScan)
    {
      if (cliActive())
      {
        allowAutoScan = false;
      }

      if ((millis() - bootTick) > 5000)
      {
        flockScan.scan("");
        allowAutoScan = false;
      }
    }
  }

  // user LED continually flashes - visual heartbeat
  if ((millis() - msFlash) > 500) {
    msFlash = millis();
    digitalWrite(USER_LED, !digitalRead(USER_LED));
  }

  // check the stack every 2 seconds
  if ((millis() - msHeap) > 2000) {
    msHeap = millis();
    heapCheck();
  }
}

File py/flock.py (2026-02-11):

#!/usr/bin/python3

import argparse
import json
import sqlite3
import sys
import time

import serial
import yaml


class surveyJson:
    def __init__(self, raw: str) -> None:
        self._json = None
        self._wifiInx = 0
        self._wifiCount = 0
        self._bleInx = 0
        self._bleCount = 0

        self._loadSurvey(raw)

    def _loadSurvey(self, data: str) -> bool:
        self._json = json.loads(data)

        self._wifiCount = len(self._json["WiFiDevices"])
        self._bleCount = len(self._json["BLEDevices"])
        return True

    def getWiFiDevCount(self) -> int:
        return self._wifiCount

    def getBLEDevCount(self) -> int:
        return self._bleCount

    def getItem(self, key: str):
        try:
            return self._json[key]
        except KeyError:
            return None

    def getHeader(self):
        device = self.getItem("Device")
        notes = self.getItem("SurveyNotes")
        dateTime = self.getItem("DateTime")
        longitude = self.getItem("LocationLongLat")[1]
        lattitude = self.getItem("LocationLongLat")[0]
        satCount = self.getItem("SatelliteCount")
        version = self.getItem("DataVersion")

        # if we haven't established GPS, set long/lat to zeroes
        if longitude is None:
            longitude = 0
        if lattitude is None:
            lattitude = 0

        if (
            notes == None
            or device == None
            or dateTime == None
            or longitude == None
            or lattitude == None
            or satCount == None
        ):
            return None

        else:
            return (notes, device, version, dateTime, longitude, lattitude, satCount)

    def getNextWifiDevice(self):
        if self._wifiInx >= self._wifiCount:
            return None

        try:
            type = self._json["WiFiDevices"][self._wifiInx]["Type"]
            subtype = self._json["WiFiDevices"][self._wifiInx]["Subtype"]
            ssid = self._json["WiFiDevices"][self._wifiInx]["SSID"]
            sourceAddr = self._json["WiFiDevices"][self._wifiInx]["SourceAddr"]
            destAddr = self._json["WiFiDevices"][self._wifiInx]["DestAddr"]
            channel = self._json["WiFiDevices"][self._wifiInx]["Channel"]
            rssi = self._json["WiFiDevices"][self._wifiInx]["RSSI"]
            relatime = self._json["WiFiDevices"][self._wifiInx]["Relatime"]
        except KeyError as e:
            print(e)
            return None

        self._wifiInx = self._wifiInx + 1

        return (type, subtype, ssid, sourceAddr, destAddr, channel, rssi, relatime)

    def getNextBTDevice(self):
        if self._bleInx >= self._bleCount:
            return None

        uuid16 = []
        uuid32 = []
        uuid128 = []
        duuid16 = []
        duuid32 = []
        duuid128 = []

        try:
            name = self._json["BLEDevices"][self._bleInx]["Name"]
            mac = self._json["BLEDevices"][self._bleInx]["MAC"]
            rssi = self._json["BLEDevices"][self._bleInx]["RSSI"]
            relatime = self._json["BLEDevices"][self._bleInx]["Relatime"]
        except KeyError:
            return None

        try:
            uuid16 = self._json["BLEDevices"][self._bleInx]["UUID16bit"]
        except KeyError:
            pass

        try:
            uuid32 = self._json["BLEDevices"][self._bleInx]["UUID32bit"]
        except KeyError:
            pass

        try:
            uuid128 = self._json["BLEDevices"][self._bleInx]["UUID128bit"]
        except KeyError:
            pass

        try:
            duuid16 = self._json["BLEDevices"][self._bleInx]["DataUUID16bit"]
        except KeyError:
            pass

        try:
            duuid32 = self._json["BLEDevices"][self._bleInx]["DataUUID32bit"]
        except KeyError:
            pass

        try:
            duuid128 = self._json["BLEDevices"][self._bleInx]["DataUUID128bit"]
        except KeyError:
            pass

        self._bleInx = self._bleInx + 1

        return (
            name,
            mac,
            rssi,
            uuid16,
            uuid32,
            uuid128,
            duuid16,
            duuid32,
            duuid128,
            relatime,
        )


class sq3db:
    def __init__(self, fileName: str) -> None:
        self._dbConnection = sqlite3.connect(fileName)
        self._cursor = self._dbConnection.cursor()
        self._membersExists = False
        self._servicesExists = False

        self._createTables()
        self._loadYaml()
        self._loadMac()

    def _createTables(self) -> bool:
        try:
            self._cursor.execute("""
                    CREATE TABLE IF NOT EXISTS surveys (
                        surveyInx INTEGER PRIMARY KEY AUTOINCREMENT,
                        version INTEGER NOT NULL,
                        device TEXT NOT NULL,
                        notes TEXT NOT NULL,
                        dateTime TEXT NOT NULL,
                        longitude REAL NOT NULL,
                        lattitude REAL NOT NULL,
                        satCount INTEGER NOT NULL
                    );
            """)
        except sqlite3.OperationalError as ex:
            print(ex)

        try:
            self._cursor.execute("""
                    CREATE TABLE IF NOT EXISTS wifi_data (
                        wifiInx INTEGER PRIMARY KEY AUTOINCREMENT,
                        surveyInx INTEGER NOT NULL,
                        subtype TEXT NOT NULL,
                        relatime INTEGER NOT NULL,
                        sourceAddr TEXT NOT NULL,
                        destAddr TEXT NOT NULL,
                        rssi INTEGER NOT NULL,
                        channel INTEGER NOT NULL,
                        FOREIGN KEY (surveyInx)
                            REFERENCES surveys (surveyInx)
                                ON DELETE CASCADE
                                ON UPDATE NO ACTION
                    );
            """)
        except sqlite3.OperationalError as ex:
            print(ex)

        try:
            self._cursor.execute("""
                    CREATE TABLE IF NOT EXISTS wifi_management (
                        wifiInx INTEGER PRIMARY KEY AUTOINCREMENT,
                        surveyInx INTEGER NOT NULL,
                        subtype TEXT NOT NULL,
                        relatime INTEGER NOT NULL,
                        ssid TEXT NOT NULL,
                        bssid TEXT NOT NULL,
                        rssi INTEGER NOT NULL,
                        channel INTEGER NOT NULL,
                        FOREIGN KEY (surveyInx)
                            REFERENCES surveys (surveyInx)
                                ON DELETE CASCADE
                                ON UPDATE NO ACTION
                    );
            """)
        except sqlite3.OperationalError as ex:
            print(ex)
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

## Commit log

2025-11-14 adding CLI and some hardware stuff
    [FlockOff-B_Cu.gbr, FlockOff-B_Mask.gbr, FlockOff-B_Paste.gbr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]
2025-11-20 using hasher from esp32 core
2025-11-20 starting kunga refactoring. Adding custom partition scheme. Arduino IDE sucks for refactoring - where's the 'clean' function (like make clean)???
    [partitions.csv]
2025-11-22 rework of wifi detection to actually be logical; starting to replace naked arrays with STL containers where it makes sense.
    [cli.cpp, flockFs.cpp, scanner.cpp]
2025-11-30 Moving from proto to first version hardware, including addressible LEDS
2025-11-30 Fix pads for LEDs
2025-12-07 reworking config, start of debug logging, fixup PCB a bit
    [Flocker.ino, cli.cpp, flockCfg.cpp]
2025-12-10 moar logging
    [FlockOff.kicad_pcb]
2025-12-17 fix logger timing issue. Added known assigned numbers from bluetooth org to python database driver
    [flock.py]
2026-01-04 adding dev instructions, fixing python scripts for mac python3
    [flock.py]
2026-01-04 adding start of 3d printed case model
    [case.scad]
2026-01-07 working on case
    [case.scad]
2026-01-07 moar case work. ugh.
    [case.scad]
2026-01-07 first draft of (ugly) case done, ready to test print
    [bottom.stl, case.scad, top.stl]
2026-01-08 Updated case. Tres fancy! :D
    [bottom.stl, case.scad, top.stl]
2026-01-09 Moar case (#4)
    * Adding lanyard ring to case, re-rendering .stl files
    * new docs
    [bottom.stl, case.scad, top.stl]
2026-01-10 added 1mm to top to better handle counterbore of 3mm SHCS
    [bottom.stl, case.scad, top.stl]
2026-01-10 Moar case (#6)
    * added 1mm to top to better handle counterbore of 3mm SHCS
    * some docs
    * ope, forgot to MarkDown like an image
    * documenting
    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
2026-01-11 Fixed bt scan memory leak (#7)
    [scanner.cpp]
2026-01-12 Fix scanner bugs (#8)
    * Fixed bt scan memory leak
    * cleaning up some cruft
    [flockCfg.cpp]
2026-01-13 fix allocation/free, docs docs docs (#11)
    [flockCfg.cpp]
2026-01-14 Merge added WiFi functionality into main (#14)
    * fix allocation/free, docs docs docs
    * Missed a file in docs
    * Add more wifi packets (#13)
    * Adding general data WiFI packets
    * Adding WiFi data packet gathering, major (breaking) database and python changes
    [flock.py, scanner.cpp]
2026-01-15 Added 'version' command, changed database schema to add device name to surveys table, updated scanner to tweak BT duration. Changes to example sql and python script to go with DB schema changes. (#15)
2026-01-17 Increase survey buffer size (due to more wifi devices found). Update ls command to show file last modified data/time
2026-01-19 Starting scan cmd (#17)
    * starting framework for scan command, added config values, adding scan update method
    * continuous scan and autoscan in place; needs filtering
2026-01-21 Add match criteria (#18)
    * beginning to add match criteria handler
    * Added new Allocator class for STL types to go into PS_RAM instead of SRAM, added python script to get OUIs from json, add matching stuff
2026-01-21 Add match criteria (#19)
    * Missed this file in last PR
    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
    [flock.py]
2026-01-21 updated header image, copyright date; corrected reversed lat/long (#20)
    [cli.cpp]
2026-02-11 Add 32bit uuids, db schema update, bug fixes (#24)
    * Adding UUID32 size BT data and service
    * Updating sample SQL queries and fixing bug with python
    [cli.cpp, flock.py, scanner.cpp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]
